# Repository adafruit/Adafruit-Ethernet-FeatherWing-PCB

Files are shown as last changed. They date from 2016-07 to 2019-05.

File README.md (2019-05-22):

## Adafruit Ethernet FeatherWing PCB
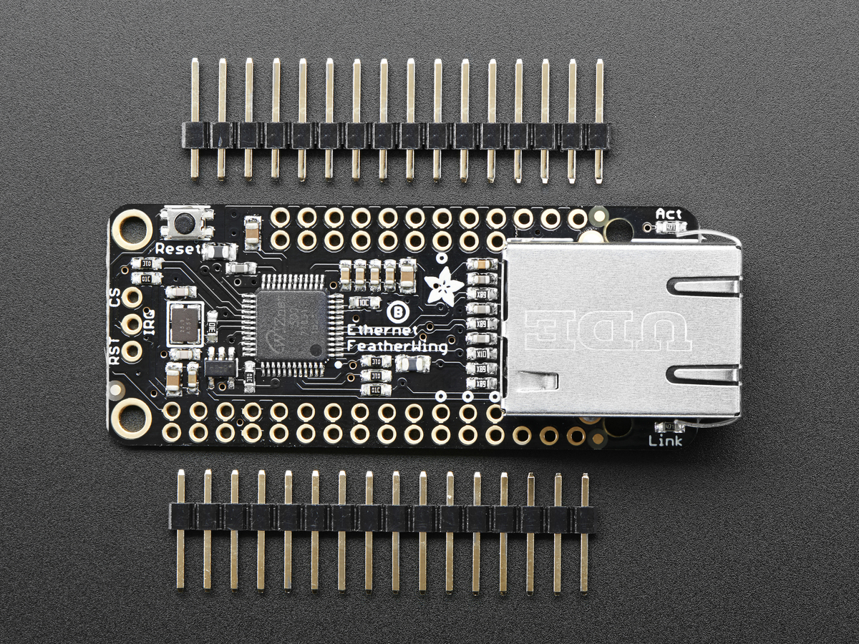
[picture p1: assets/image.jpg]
<a href="http://www.adafruit.com/products/3201"><br/>
Click here to purchase one from the Adafruit shop</a>

Wireless is wonderful, but sometimes you want the strong reliability of a wire. If your Feather board is going to be part of a permanent installation, this Ethernet FeatherWing will let you add quick and easy wired Internet. Just plug in a standard ethernet cable, and run the Ethernet2 library for cross-platform networking. Works with all/any of our Feather boards as an Ethernet Client (server not supported at this time)!

Ethernet is a tried-and-true networking standard. It's supported by every hub and switch, and because there's a physical connection you don't have to noodle around with SSIDs, passwords, authentication schemes or antennas. It works great with any of our Feathers, the WIZ5500 chip communicates over SPI plus a single CS pin. The Arduino Ethernet2 library works great, and within a few seconds after connecting, will do the DHCP setup for you. As a nice extra, the RJ-45 jack has both link and activity lights that will light/blink to let you know the current connection status.

PCB files for the Adafruit  Ethernet FeatherWing. The format is EagleCAD schematic and board layout
- https://www.adafruit.com/products/3201

### License

Adafruit invests time and resources providing this open source design, please support Adafruit and open-source hardware by purchasing products from [Adafruit](https://www.adafruit.com)!

All text above must be included in any redistribution

Designed by Limor Fried/Ladyada for Adafruit Industries.
Creative Commons Attribution/Share-Alike, all text above must be included in any redistribution. 
See license.txt for additional information.

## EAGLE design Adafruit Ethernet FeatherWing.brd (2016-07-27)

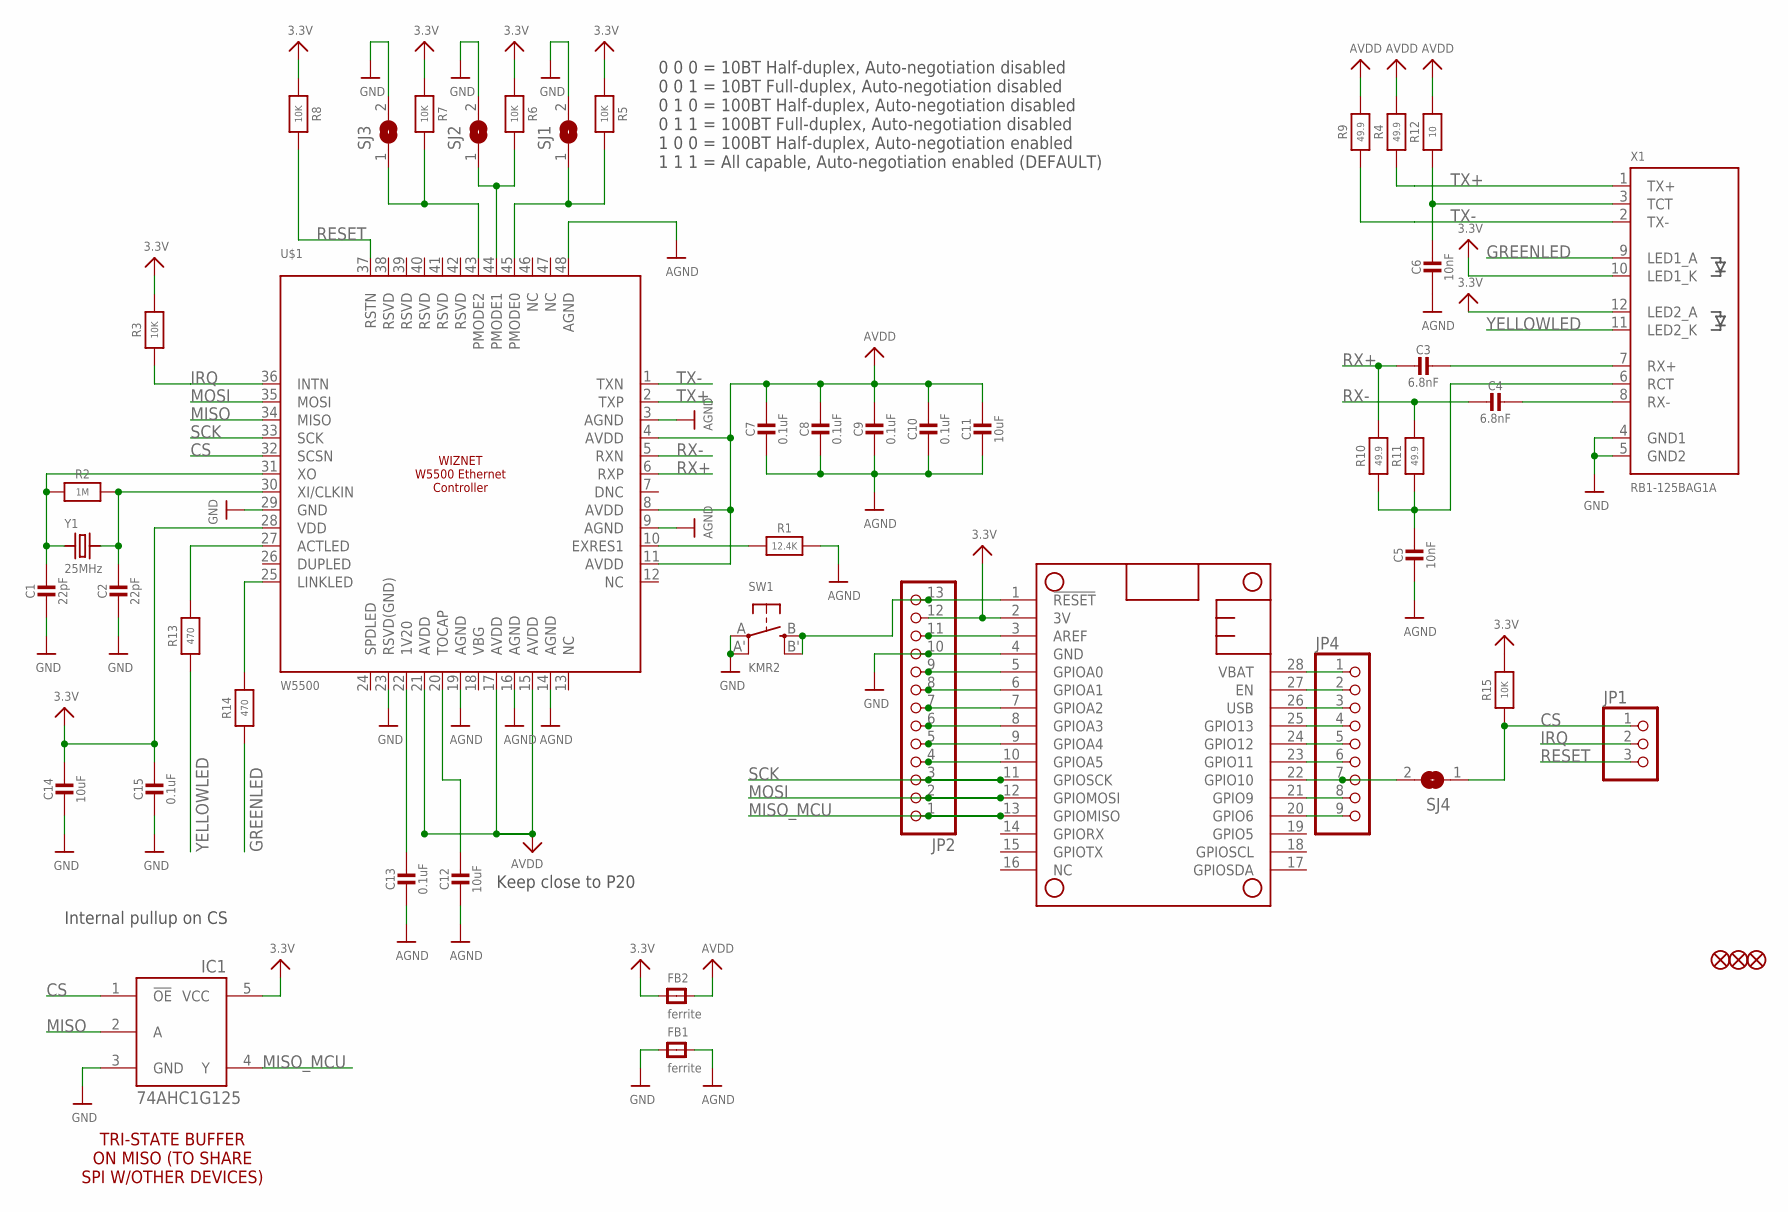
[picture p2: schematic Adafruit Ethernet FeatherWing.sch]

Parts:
C1, C2: 22pF; 0603-NO
C3, C4: 6.8nF; 0603-NO
C5, C6: 10nF; 0603-NO
C7, C8, C9, C10, C13, C15: 0.1uF; 0603-NO
C11, C12, C14: 10uF; 0805-NO
FB1, FB2: ferrite; 0805-NO
FID1, FID2, FID3: FIDUCIAL""; FIDUCIAL_1MM
IC1: 74AHC1G125; SOT23-5L
JP1: HEADER-1X376MIL; 1X03_ROUND_76
JP2: HEADER-1X13; 1X13_ROUND_70
JP4: HEADER-1X970MIL; 1X09_ROUND_70
MS1: FEATHERWING_NODIM
R1: 12.4K; 0603-NO
R2: 1M; 0603-NO
R3, R5, R6, R7, R8, R15: 10K; 0603-NO
R4, R9, R10, R11: 49.9; 0603-NO
R12: 10; 0603-NO
R13, R14: 470; 0603-NO
SJ1, SJ2, SJ3: SOLDERJUMPERREFLOW_NOPASTE; SOLDERJUMPER_REFLOW_NOPASTE
SJ4: SOLDERJUMPERCLOSED; SOLDERJUMPER_CLOSEDWIRE
SW1: KMR2; BTN_KMR2_4.6X2.8
U$1: W5500; LQFP48
X1: RB1-125BAG1A; RJ45_PULSEJACK
Y1: 25MHz; CRYSTAL_3.2X2.5

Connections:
3.3V: C14.1, C15.1, FB2.1, IC1.5 (VCC), JP2.12, MS1.2 (3V), R3.2, R5.1, R6.1, R7.1, R8.1, R15.2, U$1.28 (VDD), X1.10 (LED1_K), X1.12 (LED2_A)
AGND: C5.2, C6.2, C7.2, C8.2, C9.2, C10.2, C11.2, C12.2, C13.2, FB1.2, R1.2, U$1.3 (AGND), U$1.9 (AGND), U$1.14 (AGND), U$1.16 (AGND), U$1.19 (AGND), U$1.48 (AGND)
AVDD: C7.1, C8.1, C9.1, C10.1, C11.1, FB2.2, R4.2, R9.2, R12.2, U$1.4 (AVDD), U$1.8 (AVDD), U$1.11 (AVDD), U$1.15 (AVDD), U$1.17 (AVDD), U$1.21 (AVDD)
CS: IC1.1 (!OE), JP1.1, R15.1, SJ4.1, U$1.32 (SCSN)
GND: C1.2, C2.2, C14.2, C15.2, FB1.1, IC1.3 (GND), JP2.10, MS1.4 (GND), SJ1.2, SJ2.2, SJ3.2, SW1.A, SW1.A' (P1), U$1.23 (RSVD(GND)), U$1.29 (GND), X1.4 (GND1), X1.5 (GND2)
GREENLED: R14.1, X1.9 (LED1_A)
IRQ: JP1.2, R3.1, U$1.36 (INTN)
MISO: IC1.2 (A), U$1.34 (MISO)
MISO_MCU: IC1.4 (Y), JP2.1, MS1.13 (GPIOMISO)
MOSI: JP2.2, MS1.12 (GPIOMOSI), U$1.35 (MOSI)
unnamed: C1.1, R2.1, U$1.31 (XO), Y1.1
unnamed: C2.1, R2.2, U$1.30 (XI/CLKIN), Y1.2
unnamed: R1.1, U$1.10 (EXRES1)
unnamed: R5.2, SJ1.1, U$1.45 (PMODE0)
unnamed: R6.2, SJ2.1, U$1.44 (PMODE1)
unnamed: R7.2, SJ3.1, U$1.43 (PMODE2)
unnamed: C3.1, X1.7 (RX+)
unnamed: C4.1, X1.8 (RX-)
unnamed: C5.1, R10.1, R11.1, X1.6 (RCT)
unnamed: C6.1, R12.1, X1.3 (TCT)
unnamed: C13.1, U$1.22 (1V20)
unnamed: C12.1, U$1.20 (TOCAP)
unnamed: R13.2, U$1.27 (ACTLED)
unnamed: R14.2, U$1.25 (LINKLED)
unnamed: JP4.2, MS1.27 (EN)
unnamed: JP4.4, MS1.25 (GPIO13)
unnamed: JP4.5, MS1.24 (GPIO12)
unnamed: JP4.6, MS1.23 (GPIO11)
unnamed: JP4.7, MS1.22 (GPIO10), SJ4.2
unnamed: JP4.8, MS1.21 (GPIO9)
unnamed: JP4.9, MS1.20 (GPIO6)
unnamed: JP2.13, MS1.1 (!RESET), SW1.B (S), SW1.B' (S1)
unnamed: JP2.4, MS1.10 (GPIOA5)
unnamed: JP2.5, MS1.9 (GPIOA4)
unnamed: JP2.6, MS1.8 (GPIOA3)
unnamed: JP2.7, MS1.7 (GPIOA2)
unnamed: JP2.8, MS1.6 (GPIOA1)
unnamed: JP2.9, MS1.5 (GPIOA0)
unnamed: JP2.11, MS1.3 (AREF)
RESET: JP1.3, R8.2, U$1.37 (RSTN)
RX+: C3.2, R10.2, U$1.6 (RXP)
RX-: C4.2, R11.2, U$1.5 (RXN)
SCK: JP2.3, MS1.11 (GPIOSCK), U$1.33 (SCK)
TX+: R4.1, U$1.2 (TXP), X1.1 (TX+)
TX-: R9.1, U$1.1 (TXN), X1.2 (TX-)
USB: JP4.3, MS1.26 (USB)
VBAT: JP4.1, MS1.28 (VBAT)
YELLOWLED: R13.1, X1.11 (LED2_K)

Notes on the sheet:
0 0 0 = 10BT Half-duplex, Auto-negotiation disabled 0 0 1 = 10BT Full-duplex, Auto-negotiation disabled 0 1 0 = 100BT Half-duplex, Auto-negotiation disabled 0 1 1 = 100BT Full-duplex, Auto-negotiation disabled 1 0 0 = 100BT Half-duplex, Auto-negotiation enabled 1 1 1 = All capable, Auto-negotiation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
Internal pullup on CS
Keep close to P20
TRI-STATE BUFFER ON MISO (TO SHARE SPI W/OTHER DEVICES)

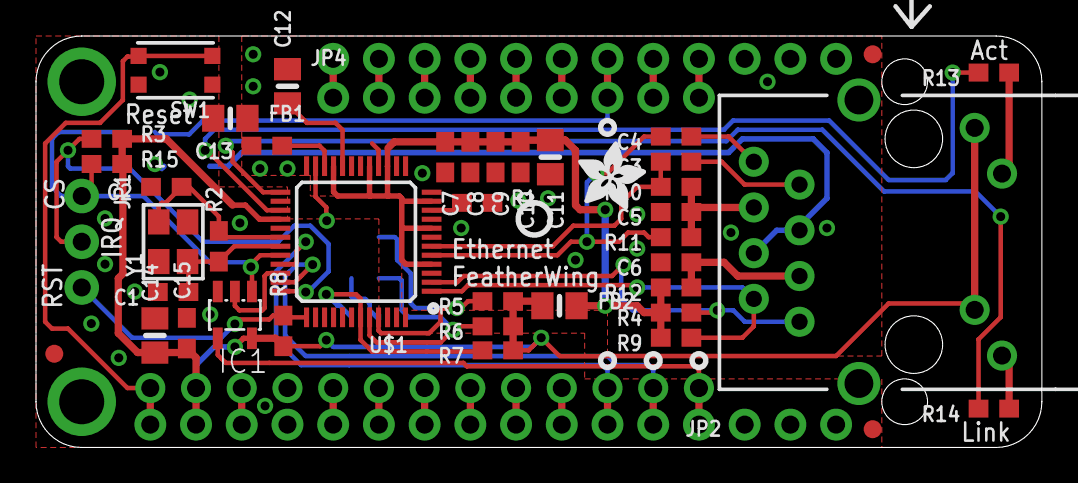
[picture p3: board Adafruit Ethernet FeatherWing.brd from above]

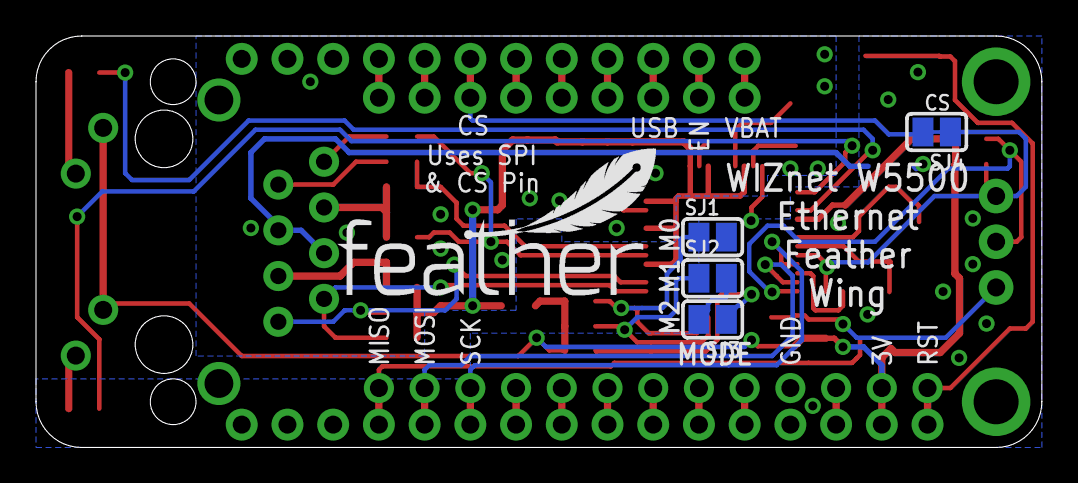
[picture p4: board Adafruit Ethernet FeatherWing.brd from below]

Board: 2 copper layers, 55.9 x 22.9 mm, 51 parts (5 on the bottom side), 48 nets.

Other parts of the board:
U$45: PCBFEAT-REV-040
U$48: FEATHERLOGO_MED
U$49: ADAFRUIT_3.5MM

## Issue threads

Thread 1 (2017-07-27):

Board routing

anidea, 2017-07-27:
The quality of routing on this board is low.  It should be used to copy from.  The decoupling alone is poor.  I'm honestly amazed it works.  Analog 3.3V shown.

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

ladyada, 2017-07-27:
submit a commit with better routing and we will check it out, thx!

anidea, 2017-07-27:
I have it in Altium.  Would that be worth sharing?  I mostly wanted to point it out so that someone else using this design would be aware.

ladyada, 2017-07-27:
hiya, please update the original eagle file, that way we can update it with your awesome routing!

Closed 2017-07-27.

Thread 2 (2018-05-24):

Adding hardware MAC address.

berossm, 2018-05-24:
As currently implemented use requires either updating the source to have a hard coded mac address or some other external source.  This becomes an issue when more than 1 or 2 are on the same development network.

The approach we have used for working with W5500 on products was the 24AA025E48T-I/OT.
http://ww1.microchip.com/downloads/en/DeviceDoc/24AA02E48-24AA025E48-24AA02E64-24AA025E64-Data-Sheet-20002124H.pdf

This is an 400kHz I2C device.  We selected this particular part because it the SOT23-6 has 2 address lines for some added flexibility in avoiding address conflict.  This would end up using a Microchip OUI if using the stock part but the data sheet list Factory Programming.
The Ethernet2 library could then be updated to make use of this new feature.

Routing could be very tricky give the location of the SCL/SDA lines with respect to the RJ45 connector.  We don't do layout in house so that is a little outside of my comfort area.

abcd-ca, 2019-05-27:
@berossm @ladyada

Here's my solution for having a unique mac address when using multiple devices with Ethernet Featherwing on the same network. Relies on the unique chip id on the ESP.

https://gist.github.com/abcd-ca/556e67d09e5619b2dd534c173b65624b

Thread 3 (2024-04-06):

CS on bottom silkscreen is aligned to the wrong pin

jjuliano77, 2024-04-06:
While trying to use an Ethernet FeatherWing in a  non-Feather project, I discovered that the bottom side CS marking is on D11, not D10. Since I needed to solder wires directly to the bottom side for my application, it actually took me a while to figure out why it wasn't working.

It's a small issue, but I thought it was worth mentioning, and there is no easy way to do a PR for something like that.

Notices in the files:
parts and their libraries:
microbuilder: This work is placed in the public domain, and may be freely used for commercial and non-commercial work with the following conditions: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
